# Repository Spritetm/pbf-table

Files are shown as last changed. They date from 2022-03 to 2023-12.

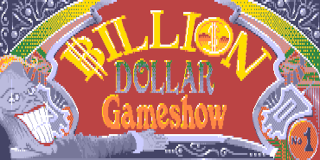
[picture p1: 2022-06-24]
esp32/components/emu_esp32s3_bindings/img/table3.png

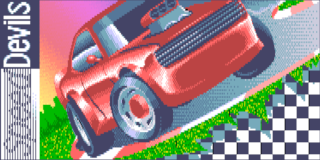
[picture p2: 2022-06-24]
esp32/components/emu_esp32s3_bindings/img/table2.png

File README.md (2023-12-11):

# Pinball Fantasies physical virtual pinball table

These are the firmware, case designs, schematics and PCB artwork
for the tiny video pinball table as described [here](https://spritesmods.com?art=pftable).

# Firmware

The firmware consists of a core emulator that emulates the main game
logic, a music player to replace the audio subsystem, and bindings
for graphics, input, and audio playback for various situations.

There are three builds for the firmware:

- Host build. For this, make sure you have the SDL2 development libraries
  installed and run ``make`` ``in the esp32/components/emu`` folder. You
  should get an ``emu`` binary using that. Use lshift, rshift, F1 and 
  enter to control the emulator.
- ESP32 build for ESP-Wrover-Kit
  This needs a wrover with >=8MiB of flash (and >=2MiB of psram). Use
  ``idf.py set-target esp32`` to select this and build and flash 
  using standard esp-idf procedures. You need buttons to control these,
  for start, plunger, left flipper and right flipper respectively, 
  connect buttons from GPIO 14, 13, 15 and 12 to ground. Audio signal
  comes out of GPIO26. Note that the game does not run at full frame
  rate on an ESP32 as the code is not optimized for that chip.
- ESP32S3 on custom PCB.
  This needs the pcbs from the ``pcb/`` and ``pcb-backbox-large/`` fabricated
  and assembled. Use ``idf.py set-target esp32s3`` and build and flash
  according to standard esp-idf procedures.

Note that the ESP32 and ESP32-S3 targets also need the Pinball 
Fantasies data files flashed; the Unix build simply needs them to
exist in the data directory. Details and helpers for obtaining these
files is in the ``data/README.md`` file. There is an example script for
flashing in ``esp32/flashdata.sh``, but it may need modifying for your
particular setup.

# Case

There is a case design (made in OpenSCAD) in the ``case`` subdirectory. 
Note that the measures are mostly what works on my 3d-printer; you 
may need to print this, see if it fits, then print again to get a 
working case.

The case parts are held together by two m3 screws fitting in two 4x5mm
brass screw thread inserts. I simply super-glued the inserts in place.

# PCB

There are three folders with Kicad PCBs: ``pcb``, ``pcb-backboard`` and 
``pcb-backboard-large``. ``pcb`` contains the main PCB which fits under
the main playfield LCD. ``pcb-backboard-large`` contains the PCB I used
for the final backboard, it interfaces with a 2.3" 320x240 LCD. ``pcb-backboard``
is a previous iteration of this; it has an 1.5" 240x240 LCD on it; it 
is included for reference only.

Note: You must use an ESP32-S3 module that has 2 or more megabyte of
QUAD PSRAM onboard. A module with octal PSRAM (or octal flash) will
not function, as it needs GPIOs that are used for other things.

# Components

Most of the components are indicated on the PCBs, but some are connected
using JST-PH or JST-XH connectors. Here's a short list of what goes where:

- J2: Speaker. I used a 4 ohm, 1.5W speaker from a laptop I had around.
- J3: Connected to an 10uF MLCC SMD cap used as the plunger sensor. The 
  plunger mechanics physically hit this cap when slamming back. See
  article on how that works.
- J4: LiIon/LiPo battery. I used a generic 1000mAh, 3.7V cell I had around.
- J5: Horizontal and vertical linear haptic actuators. These actuators are
  spare parts for a Huawei Mate 30 Pro.
- J6: Flipper and start buttons. These are a 4*5.6 HD11 microswitch each.
  Note that if you use something else, you may need to change the case model
  to make them fit.

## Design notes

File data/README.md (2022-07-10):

# Pinball Fantasies data files

This folder should contain the data files to run Pinball Fantasies, plus 'table-screens.bin' which
contains screenshots of the various tables in VGA memory dump format.

# How to get the data files

Easiest legal way:
- Buy the Pinball Gold Pack on GOG: https://www.gog.com/en/game/pinball_gold_pack
- This should make Pinball Fantasies Deluxe show up in your library. Download and install it.
- From the installed Pinball Fantasies Deluxe directory, find data/game.gog.
- Copy data/game.gog into this directory.
- Make sure you have Dosbox installed.
- Start dosbox in the current directory
- The dosbox main screen should pop up with '12 files copied' and the command prompt at the bottom
  of the screen. This means the files were succesfully extracted.
- Enter 'exit' to close dosbox.
- Remove game.gog.

Note that if you get your datafiles elsewhere and want to run this on an ESP32, you may need
to modify the filesizes in mmap_file_esp32.c.

# How to rebuild 'table-screens.bin'

The file is included in the Git repo as I imagine some screenshots easily fall under 'fair use',
but in case you want to rebuild it, here's how:

- Compile Unix build of the emulator (it's located in esp32/components/main/emu, refer to
  the README.md there to build it)
- Load up table 1
- Press 't' to dump a screenshot of the table as vram.bin and vram.pal
- Rename those files to vram1.bin and vram1.pal
- Repeat for tables 2, 3, 4
- cat vram1.bin vram1.pal vram2.bin vram2.pal vram3.bin vram3.pal vram4.bin vram4.pal > table-screens.bin

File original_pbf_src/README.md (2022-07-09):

These are the sources available from
https://github.com/historicalsource/pinballfantasies
but re-encoded into UTF8, plus some lines translated from
Swedish to english, plus a failed attempt to get this mess 
to assemble. I'll leave the Makefile and other notes in place
in case someone else wants to have a go at it.

Step 1: iconv -f CP850 -t utf-8 [all-files]
Step 2: swedish -> english

'should be compatible' masm variant:
uasm - https://github.com/Terraspace/UASM but check PRs on compile fixes
make using 'make -f gccLinux64.mak'

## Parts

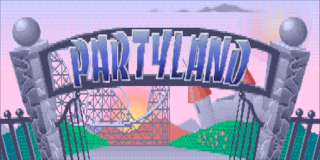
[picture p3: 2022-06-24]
esp32/components/emu_esp32s3_bindings/img/table1.png

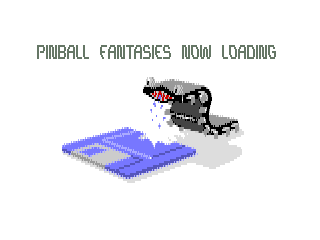
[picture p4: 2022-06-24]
esp32/components/emu_esp32s3_bindings/img/loading.png

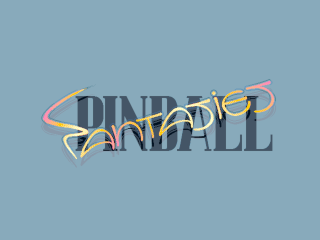
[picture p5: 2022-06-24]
esp32/components/emu_esp32s3_bindings/img/pf.png

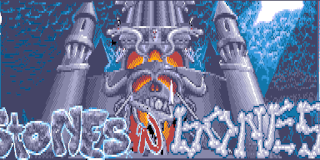
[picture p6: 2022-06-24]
esp32/components/emu_esp32s3_bindings/img/table4.png

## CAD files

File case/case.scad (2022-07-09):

/*
 * ----------------------------------------------------------------------------
 * "THE BEER-WARE LICENSE" (Revision 42):
 * Jeroen Domburg <jeroen@spritesmods.com> wrote this file. As long as you retain 
 * this notice you can do whatever you want with this stuff. If we meet some day, 
 * and you think this stuff is worth it, you can buy me a beer in return. 
 * ----------------------------------------------------------------------------
 */


//build_model selects what to render:
//0 - Body, backbox and button assembly cutout
//1 - Body
//2 - Backbox
//3 - Button assembly
//4 - Smattering of buttons. Pick the one that has a comfortable length. Need to cut it at the stem, the flat cylinder at the base is only for printability
//5 - A foot. Need to cut at the stem,the flat cylinder at the base is only for printability. You need four of these.
//Note that the build also uses four 2mm diameter brass rods for the legs, and some 1mm brass rod and a spring in the plunger assembly. The 1mm brass rods are also used to fix the buttons in place.
build_model=0;

mainlcd_w=42.8;
mainlcd_h=74.9;
mainlcd_lip=1;
mainlcd_extra_lip_bottom=5;
mainlcd_th=4.2; //including pcb
toplcd_w=52.8+1;
toplcd_h=46.4;
toplcd_th=2.9; //ex pcb
toplcd_pcbh=48+1.5;
toplcd_conh=9;
toplcd_conw=13.7;
toplcd_pcbth=1.7;
toplcd_conny=mainlcd_h+0.5;
toplcd_lip=1;
toplcd_slotw=(toplcd_pcbth+toplcd_th+0.5);
wall_th=2;
tolerance=0.2;
plunger_fhd=15;
plunger_bhd=15;
plunger_hw=7;
plunger_d=1.2;
plunger_height=26; //height of the actual plunger
plunger_asm_height=13; //height of the assembly
plunger_asm_offset_y=12;

insert_d=5;
insert_h=4;
insert_dist=25;

btn_l=5.9;
btn_w=4.4;
btn_h=1.7; //note: ex smd 'feet'
btn_pdia=1; //plunger dia
btn_plen=2.3; //length of plunger

knob_d=5;
knob_small_d=2.5;

speaker_w=27;
speaker_l=16;
speaker_d=1.5;
speaker_grille_dist=3;
speaker_grille_width=1;
$fn=50;


mscale=(mainlcd_w+(wall_th-mainlcd_lip)*2)/560;
pinball_base_w=560*mscale;
//pinball_base_l=1315*mscale; //official pb measure
pinball_base_l=1020*mscale+1.5; //looks better with lcd
pinball_base_minh=400*mscale;
pinball_base_maxh=605*mscale; //unused; see case_back_top
pinball_playfield_ang=8.875;

backhole_h=25;
backhole_w=pinball_base_w-2*wall_th;
case_back_top=11.0;

topbox_depth=10;

buttons_z=-11;
buttons_y=wall_th*6;

startbutton_len=buttons_y-wall_th+tolerance;

feet_d=2;
feethole_l=10;
feet_ang=12;
fq_th=4; //size of cube that holds the feet hole on the inside of the case

lact_l=15.3;
lact_w=8.2;
lact_h=2.6;
lact_tab_w=4;
lact_tab_off=3.3;


if (build_model==0) {
    intersection() {
        union() {
            pinball_body();
            translate([-mainlcd_w/2,0,-mainlcd_lip]) rotate([  pinball_playfield_ang, 0, 0]) translate([0,wall_th,-mainlcd_th]) scale(0.999) color("red") pcb();
            translate([0,pinball_base_l-topbox_depth,case_back_top]) backbox();

            translate([0,toplcd_conny,case_back_top]) color("red") backbox_stuff();
            translate([0,buttons_y,buttons_z]) button_assembly_thing();
        }
        translate([0,-100,-100]) cube([200,200,200]);
    }
} else if (build_model==1) {
    pinball_body();
} else if (build_model==2) {
    backbox();
} else if (build_model==3) {
    button_assembly_thing();
} else if (build_model==4) {
    translate([0,-6,0]) btnknob(9.5);
    translate([6,-6,0]) btnknob(9.5);
    translate([12,-6,0]) btnknob(8.5);
    translate([0,0,0]) btnknob(8.5);
    translate([6,0,0]) btnknob(7.5);
    translate([12,0,0]) btnknob(7.5);
    translate([0,6,0]) btnknob(8);
    translate([6,6,0]) btnknob(8);
    translate([12,6,0]) btnknob(9);
    translate([0,12,0]) btnknob(9);
    translate([6,12,0]) btnknob(10);
    translate([12,12,0]) btnknob(10);    
} else if (build_model==5) {
    foot();
}


module foot() {
    difference() {
        union() {
            hull() {
                sphere(d=4);
                cylinder(d=3, h=5);
            }
            cylinder(d=3, h=10);
        }
        cylinder(d=2, h=10);
        translate([0,0,7])rotate([90,0,0]) cylinder(d=0.7, h=3);
    }
    translate([0,0,8]) cylinder(d=10, h=2);
}


module pwrknob() {
    difference() {
        union() {
            translate([-1.5,0,-1]) cube([4.5,3.5,6+1]);    
            translate([-1.5-2,-2,-2.7]) cube([4.5+4,3.5+4,2.7]);        translate([-1.5-2,-2.5,-5]) cube([4.5+4,2.5,5]);
        }
        translate([0,0.4,-5]) cube([1.6,2,5]);

    }
}

module btnknob(length) {
    stem_len=8;
    rot_d=10;
    cylinder(h=1, d=knob_d);
    cylinder(h=stem_len+1, d=knob_small_d-tolerance*2);
    translate([0,0,stem_len]) cylinder(h=1, d1=knob_small_d-tolerance*2, d2=knob_d-tolerance*2);
    difference() {
        intersection() {
            translate([0,0,stem_len+1]) cylinder(h=length*2, d=knob_d-tolerance*2);
            translate([0,0,stem_len+length-rot_d/2]) sphere(d=rot_d);
        }
        hull() {
            translate([0,0,stem_len+2.2]) rotate([90,0,0]) cylinder(h=10, d=1.2, center=true);
            translate([0,0,stem_len+2.2+3]) rotate([90,0,0]) cylinder(h=10, d=1.2, center=true);
        }
    }
}


module button_assembly_thing() {
    difference() {
        btnholder_l=btn_l+wall_th/2;
        btnholder_w=knob_d+wall_th/2;
        union() {
           translate([-(btnholder_l+btnholder_w/2), 0, 0]) rotate([0,0,90]) button_assembly_pos(mainlcd_w/2-(btnholder_l+btnholder_w/2)-wall_th/2);
            translate([(btnholder_l+btnholder_w/2), 0, 0]) rotate([0,0,-90]) button_assembly_pos(mainlcd_w/2-(btnholder_l+btnholder_w/2)-wall_th/2);
            rotate([0,0,180]) button_assembly_pos(startbutton_len);
        }
        union() {
            translate([-(btnholder_l+btnholder_w/2), 0, 0]) rotate([0,0,90]) button_assembly_neg(mainlcd_w/2-(btnholder_l+btnholder_w/2)-wall_th/2);
            translate([(btnholder_l+btnholder_w/2), 0, 0]) rotate([0,0,-90]) button_assembly_neg(mainlcd_w/2-(btnholder_l+btnholder_w/2)-wall_th/2);
            rotate([0,0,180]) button_assembly_neg(startbutton_len);
        }
    }
}

module button_assembly_relief_thing() {
    btnholder_l=btn_l+wall_th/2;
    btnholder_w=knob_d+wall_th/2;
    translate([-(btnholder_l+btnholder_w/2), 0, 0]) rotate([0,0,90]) button_assembly_relief(mainlcd_w/2-(btnholder_l+btnholder_w/2)-wall_th/2);
    translate([(btnholder_l+btnholder_w/2), 0, 0]) rotate([0,0,-90]) button_assembly_relief(mainlcd_w/2-(btnholder_l+btnholder_w/2)-wall_th/2);
    rotate([0,0,180]) button_assembly_relief(startbutton_len);

}


module button_assembly_pos(length) {
    //Tray for switch
    translate([-(knob_d+wall_th)/2,-btn_l-wall_th/2,-knob_d+btn_h/2]) cube([knob_d+wall_th, btn_l+wall_th/2+length, knob_d]);
    //thing actual button is in
    translate([-(knob_d+wall_th)/2, wall_th/2, -(knob_d+wall_th)/2]) cube([knob_d+wall_th, length-wall_th/2, knob_d+wall_th]);
}

module button_assembly_neg(length) {
    //cutout for button
    translate([0,-btn_l/2,1]) cube([btn_w, btn_l, btn_h+2], center=true);
    //3mm shaft
    rotate([-90,0,0]) translate([0,0,-.1]) cylinder(d=knob_small_d+tolerance, h=length+1);
    //5mm shaft
    rotate([-90,0,0]) translate([0,0,btn_plen*2]) cylinder(d=knob_d+tolerance, h=length+wall_th*2);
    //square relief
    //translate([-(knob_d+tolerance)/2,btn_plen*2,0]) cube([knob_d+tolerance, length, knob_d]);
    //pin for holding btn
    translate([0,btn_plen*2+2+2.5,0]) rotate([0,90,0]) cylinder(d=1.1, h=knob_d+wall_th*3, center=true);
}

module button_assembly_relief(length) {
    //Tray for switch
    translate([-(knob_d+wall_th)/2-tolerance,-btn_l-wall_th/2,-knob_d+btn_h/2-tolerance]) cube([knob_d+wall_th+tolerance*2, btn_l+wall_th/2+length+tolerance, knob_d+tolerance*2]);
    //thing actual button is in
    translate([-(knob_d+wall_th)/2-tolerance, wall_th/2, -(knob_d+wall_th)/2-tolerance]) cube([knob_d+wall_th+tolerance*2, length-wall_th/2+tolerance, knob_d+wall_th+tolerance*2]);
    //5mm shaft
    rotate([-90,0,0]) translate([0,0,btn_plen*2]) cylinder(d=knob_d+tolerance, h=length+wall_th*2);
}


module screwhole() {
    rotate([-90,0,0]) union() {
        translate([0,0,-10]) cylinder(h=20, d=3.5);
        cylinder(h=10, d=5.3+0.3);
    }
}
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

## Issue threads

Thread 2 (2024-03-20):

Using a slightly different screen model (different pinout, 16bit)

opengiveback, 2024-03-20:
Hi, I intend on using the only reasonably priced screen with 360*640 and 40 wire connection I found available, same controller though. But only 16 bits for data R5G6B5. And some difference in Vcc position, lacking SPI but I2C present...
I guess I only need to rewire the FRC connector to suit the new screen (omit R6 and B6, Vcc), and find the way to init via I2C, then (perhaps) rework the bit of code that sends the 18bit color to send 16 bit instead (or just omit LSB of R and B and be content with it :) ).
But I am not the Espressif engineer here, nor have I read all the code, so here I am just asking if that seems to be enough modification of PCB and code to make it work. Or am I missing something?
Of course I shall either publish the modification in OpenSource, or provide beer as per BeerWare license. :)

Spritetm, 2024-03-21:
It should be possible to adapt the code to that display, indeed in the way you describe. Note that for this project, the angle at which you can view the display is kinda important as you tend to look at it at a 'weird' angle: make sure that your display has a wide-angle view. I made the mistake of not doing that with the top display, and it's sometimes nigh unreadable.

opengiveback, 2024-03-21:
Thanks for your expert confirmation and suggestions, author of the greatest little pinball machine ever :)
The specs on the viewing angle seem same as on the one you used (IPS, 178 degree view), and having the same controller for the display also it seems to be same physical display with different wiring configuration... either way, only others I found are more than an order of magnitude more expensive, so if it turns out they did compromise on view angles, I'll just change the angle of the screen in the product enclosure 5 degrees or so... and that should then be enough even if the screen is the lowest quality IPS screen there is... thanks again for your response

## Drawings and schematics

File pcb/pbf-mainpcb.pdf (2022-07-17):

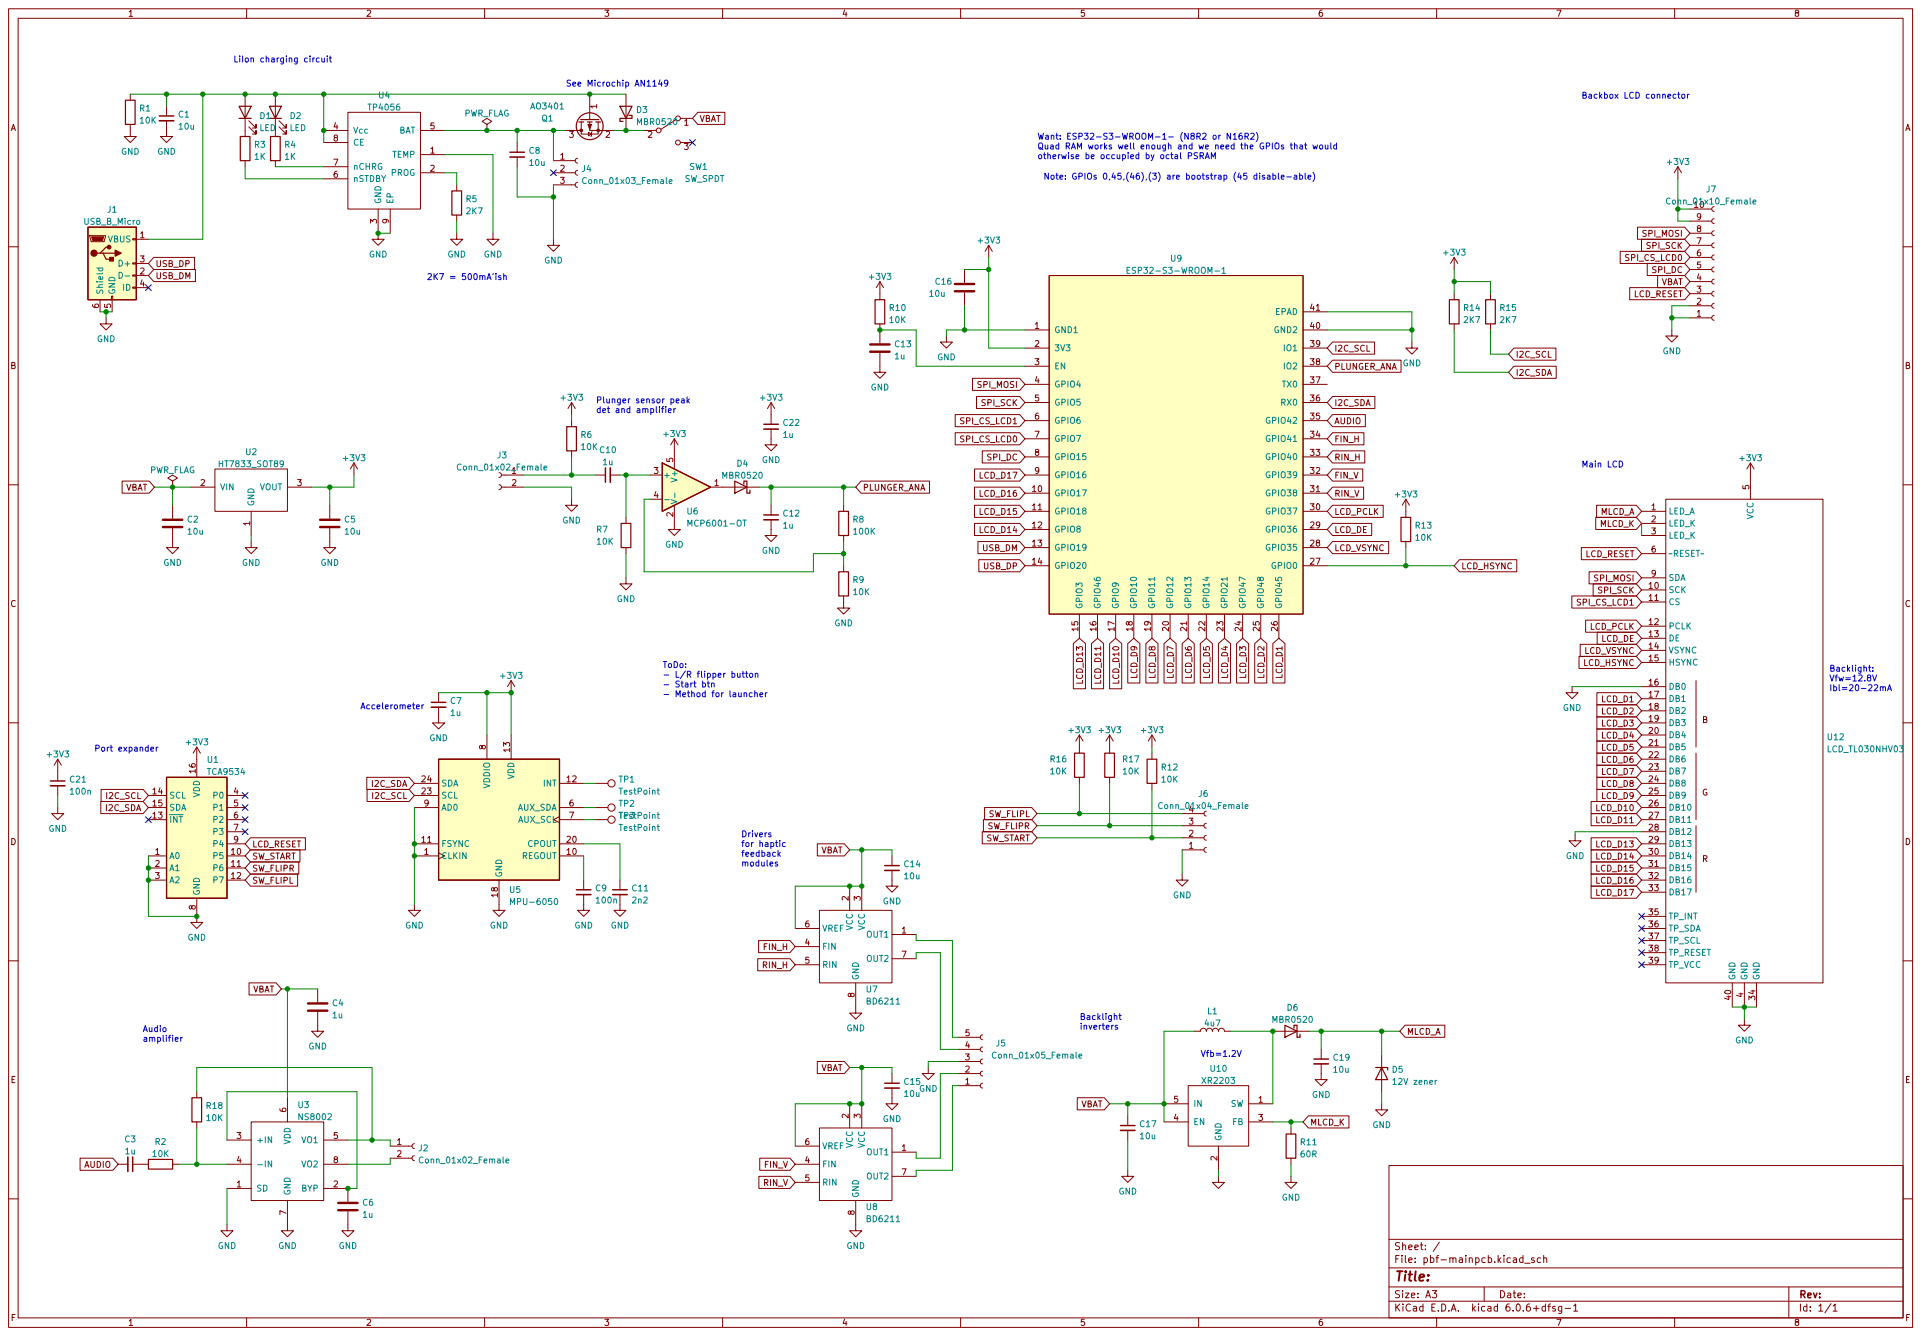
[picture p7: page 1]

Backbox LCD connector See Microchip AN1149
D3MBR0520 V- 2 V+

Want: ESP32-S3-WROOM-1- (N8R2 or N16R2)
Quad RAM works well enough and we need the GPIOs that would
otherwise be occupied by octal PSRAM

Note: GPIOs 0,45,(46),(3) are bootstrap (45 disable-able)

- Method for launcher Audio

3 FIN 4 RIN 5 VREF 6 OUT2 7 GND

File: pbf-mainpcb.kicad_sch Sheet: /

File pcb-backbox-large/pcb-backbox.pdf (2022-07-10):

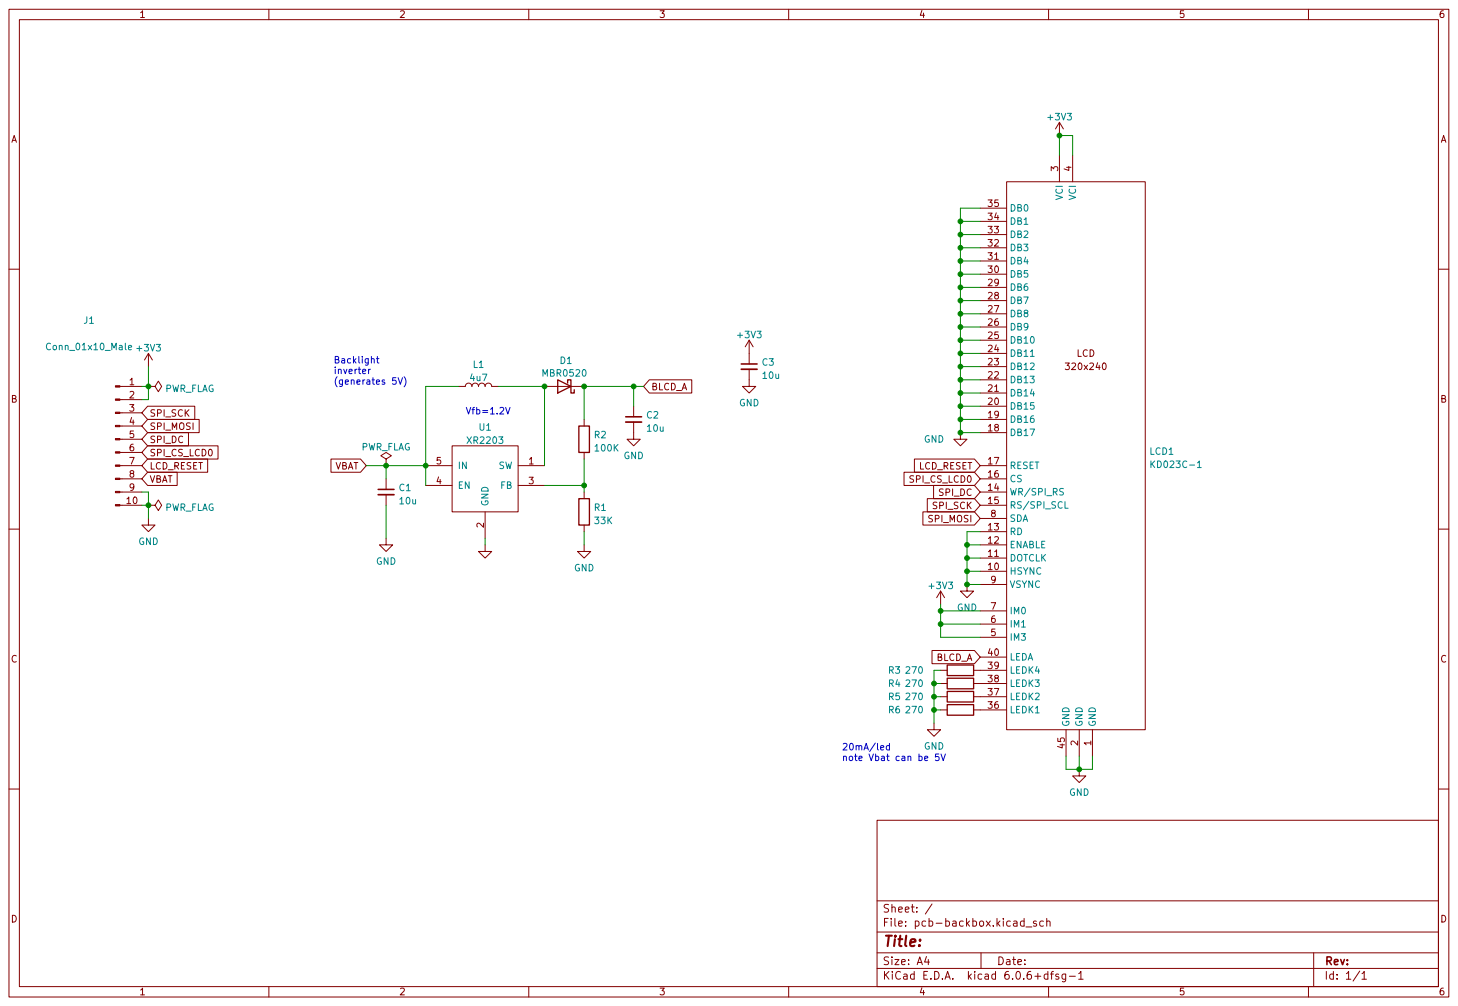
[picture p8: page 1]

20mA/led
note Vbat can be 5V

File: pcb-backbox.kicad_sch Sheet: /

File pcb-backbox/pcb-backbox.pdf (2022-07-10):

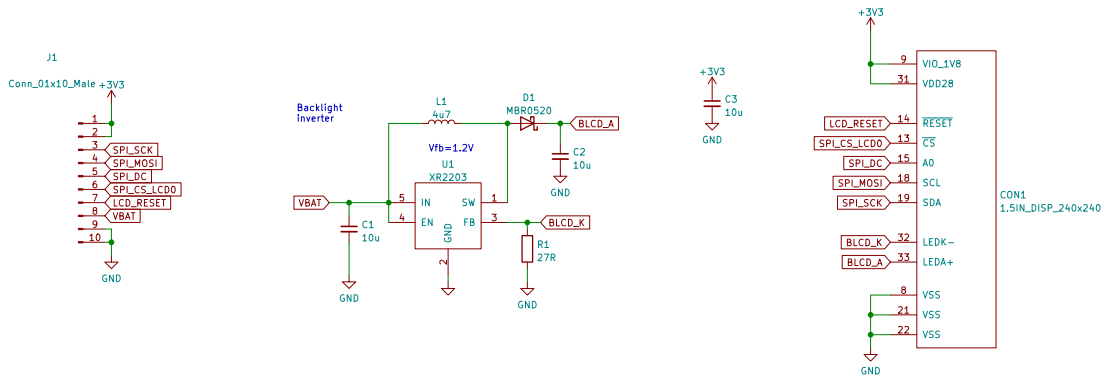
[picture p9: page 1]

File: pcb-backbox.kicad_sch Sheet: /
Id: 1/1 Title:

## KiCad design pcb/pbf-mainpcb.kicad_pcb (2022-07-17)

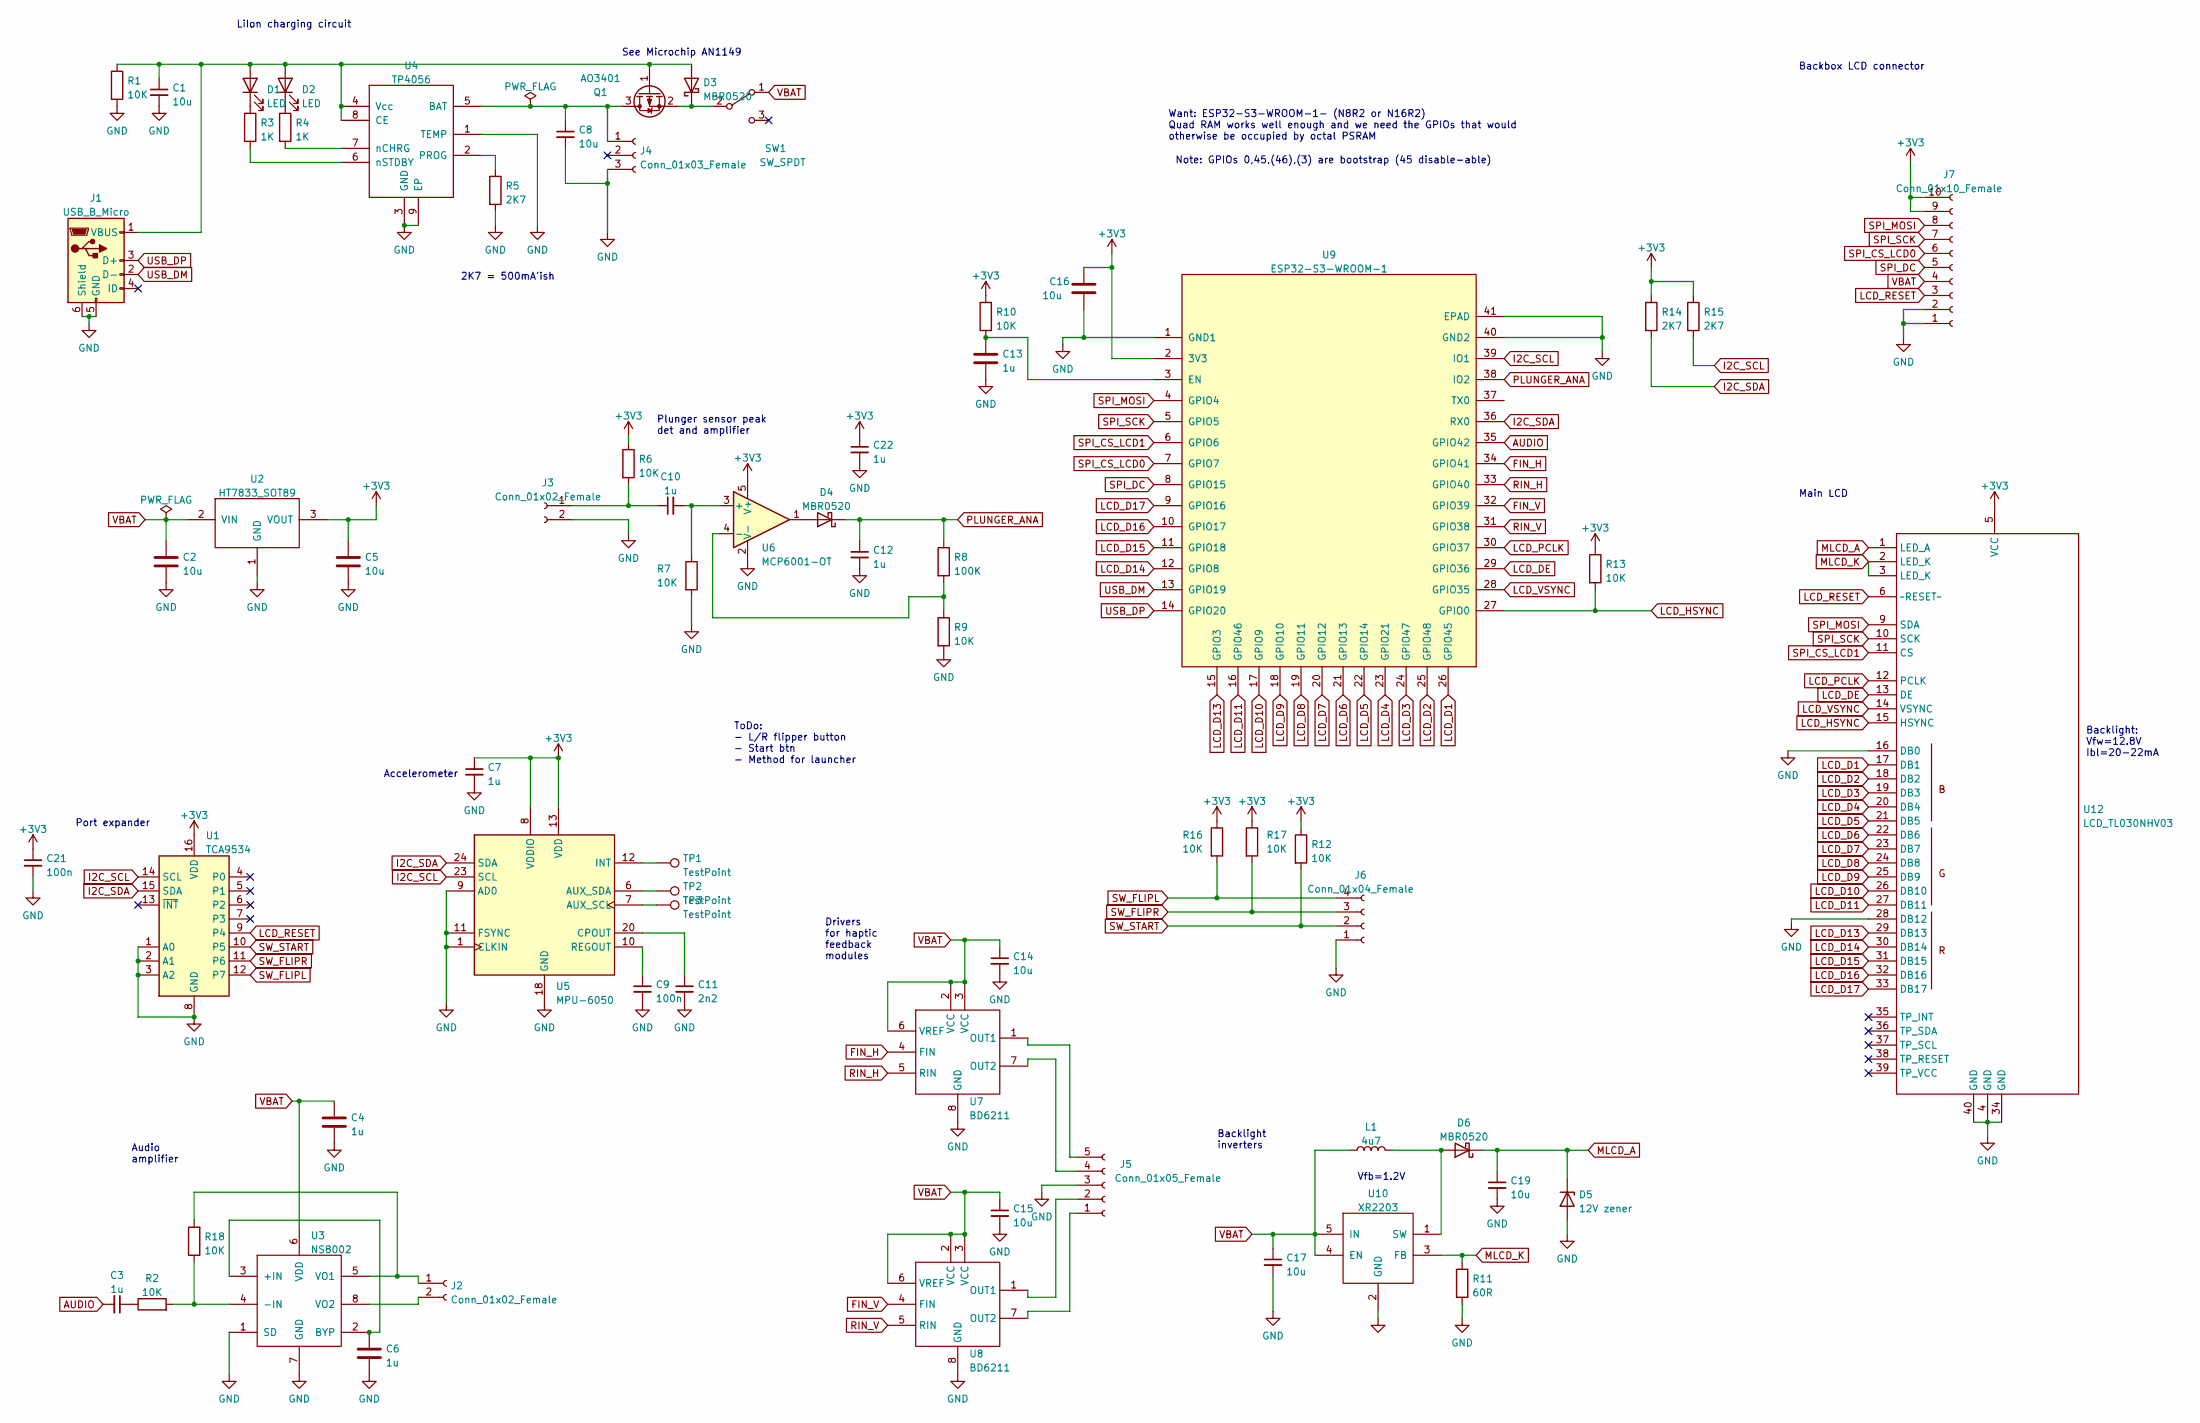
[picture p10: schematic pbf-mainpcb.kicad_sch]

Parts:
C1, C2, C5, C8, C14, C15, C16, C17, C19: 10u; C_0805_2012Metric
C3, C4, C6, C7, C10, C12, C13, C22: 1u; C_0603_1608Metric
C9, C21: 100n; C_0603_1608Metric
C11: 2n2; C_0603_1608Metric
D1, D2: LED; LED_0603_1608Metric
D3, D4, D6: MBR0520; D_SOD-123
D5: 12V zener; D_MELF
J1: USB_B_Micro; USB_Micro-B_China_MK5P
J2: Conn_01x02_Female; JST_XH_B2B-XH-AM_1x02_P2.50mm_Vertical
J3: Conn_01x02_Female; JST_PH_B2B-PH-K_1x02_P2.00mm_Vertical
J4: Conn_01x03_Female; JST_PH_B3B-PH-K_1x03_P2.00mm_Vertical
J5: Conn_01x05_Female; JST_PH_B5B-PH-K_1x05_P2.00mm_Vertical
J6: Conn_01x04_Female; JST_PH_B4B-PH-K_1x04_P2.00mm_Vertical
J7: Conn_01x10_Female; PinHeader_2x05_P2.54mm_Horizontal
L1: 4u7; L_1008_2520Metric
Q1: AO3401; SOT-23
R1, R2, R6, R7, R9, R10, R12, R13, R16, R17, R18: 10K; R_0603_1608Metric
R3, R4: 1K; R_0603_1608Metric
R5, R14, R15: 2K7; R_0603_1608Metric
R8: 100K; R_0603_1608Metric
R11: 60R; R_0603_1608Metric
SW1: SW_SPDT; SW_SPDT_PCM12
TP1, TP2, TP3: TestPoint; TestPoint_Pad_1.0x1.0mm
U1: TCA9534; TSSOP-16_4.4x5mm_P0.65mm
U2: HT7833_SOT89; SOT-89-3
U3: NS8002; SOP-8_3.9x4.9mm_P1.27mm
U4: TP4056; SOIC-8-1EP_3.9x4.9mm_P1.27mm_EP2.29x3mm
U5: MPU-6050; InvenSense_QFN-24_4x4mm_P0.5mm
U6: MCP6001-OT; SOT-23-5
U7, U8: BD6211; SOP-8_3.9x4.9mm_P1.27mm
U9: ESP32-S3-WROOM-1
U10: XR2203; SOT-23-5
U12: LCD_TL030NHV03; TE_4-1734839-0_1x40-1MP_P0.5mm_Horizontal_Reversed

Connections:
+3V3: C5.1, C7.1, C16.1, C21.1, C22.1, J7.9, J7.10, R6.1, R10.2, R12.1, R13.1, R14.1, R15.1, R16.1, R17.1, U1.16 (VDD), U2.3 (VOUT), U5.8 (VDDIO), U5.13 (VDD), U6.5 (V+), U9.2 (3V3), U12.5 (VCC)
AUDIO: C3.2, U9.35 (GPIO42)
FIN_H: U7.4 (FIN), U9.34 (GPIO41)
FIN_V: U8.4 (FIN), U9.32 (GPIO39)
I2C_SCL: R15.2, U1.14 (SCL), U5.23 (SCL), U9.39 (IO1)
I2C_SDA: R14.2, U1.15 (SDA), U5.24 (SDA), U9.36 (RX0)
LCD_D1: U9.26 (GPIO45), U12.17 (DB1)
LCD_D2: U9.25 (GPIO48), U12.18 (DB2)
LCD_D3: U9.24 (GPIO47), U12.19 (DB3)
LCD_D4: U9.23 (GPIO21), U12.20 (DB4)
LCD_D5: U9.22 (GPIO14), U12.21 (DB5)
LCD_D6: U9.21 (GPIO13), U12.22 (DB6)
LCD_D7: U9.20 (GPIO12), U12.23 (DB7)
LCD_D8: U9.19 (GPIO11), U12.24 (DB8)
LCD_D9: U9.18 (GPIO10), U12.25 (DB9)
LCD_D10: U9.17 (GPIO9), U12.26 (DB10)
LCD_D11: U9.16 (GPIO46), U12.27 (DB11)
LCD_D13: U9.15 (GPIO3), U12.29 (DB13)
LCD_D14: U9.12 (GPIO8), U12.30 (DB14)
LCD_D15: U9.11 (GPIO18), U12.31 (DB15)
LCD_D16: U9.10 (GPIO17), U12.32 (DB16)
LCD_D17: U9.9 (GPIO16), U12.33 (DB17)
LCD_DE: U9.29 (GPIO36), U12.13 (DE)
LCD_HSYNC: R13.2, U9.27 (GPIO0), U12.15 (HSYNC)
LCD_PCLK: U9.30 (GPIO37), U12.12 (PCLK)
LCD_RESET: J7.3, U1.9 (P4), U12.6 (~RESET~)
LCD_VSYNC: U9.28 (GPIO35), U12.14 (VSYNC)
MLCD_A: C19.1, D5.1 (K), D6.1 (K), U12.1 (LED_A)
MLCD_K: R11.1, U10.3 (FB), U12.2 (LED_K), U12.3 (LED_K)
unnamed: C1.1, D1.2 (A), D2.2 (A), D3.2 (A), J1.1 (VBUS), Q1.1 (G), R1.1, U4.4 (Vcc), U4.8 (CE)
unnamed: C3.1, R2.1
unnamed: C6.1, U3.2 (BYP), U3.3 (+IN)
unnamed: C8.1, J4.1, Q1.3 (D), U4.5 (BAT)
unnamed: C9.1, U5.10 (REGOUT)
unnamed: C10.1, J3.1, R6.2
unnamed: C10.2, R7.1, U6.3 (+)
unnamed: C11.1, U5.20 (CPOUT)
unnamed: C13.1, R10.1, U9.3 (EN)
unnamed: D1.1 (K), R3.1
unnamed: D2.1 (K), R4.1
unnamed: D3.1 (K), Q1.2 (S), SW1.2 (B)
unnamed: D4.2 (A), U6.1
unnamed: D6.2 (A), L1.2, U10.1 (SW)
unnamed: J2.1, R18.2, U3.5 (VO1)
unnamed: J2.2, U3.8 (VO2)
unnamed: J5.1, U8.7 (OUT2)
unnamed: J5.2, U8.1 (OUT1)
unnamed: J5.4, U7.7 (OUT2)
unnamed: J5.5, U7.1 (OUT1)
unnamed: R3.2, U4.6 (nSTDBY)
unnamed: R4.2, U4.7 (nCHRG)
unnamed: R5.1, U4.2 (PROG)
unnamed: R8.2, R9.1, U6.4 (-)
unnamed: TP1.1, U5.12 (INT)
unnamed: TP2.1, U5.6 (AUX_SDA)
unnamed: TP3.1, U5.7 (AUX_SCL)
unnamed: R2.2, R18.1, U3.4 (-IN)
PLUNGER_ANA: C12.1, D4.1 (K), R8.1, U9.38 (IO2)
RIN_H: U7.5 (RIN), U9.33 (GPIO40)
RIN_V: U8.5 (RIN), U9.31 (GPIO38)
SPI_CS_LCD0: J7.6, U9.7 (GPIO7)
SPI_CS_LCD1: U9.6 (GPIO6), U12.11 (CS)
SPI_DC: J7.5, U9.8 (GPIO15)
SPI_MOSI: J7.8, U9.4 (GPIO4), U12.9 (SDA)
SPI_SCK: J7.7, U9.5 (GPIO5), U12.10 (SCK)
SW_FLIPL: J6.4, R16.2, U1.12 (P7)
SW_FLIPR: J6.3, R17.2, U1.11 (P6)
SW_START: J6.2, R12.2, U1.10 (P5)
USB_DM: J1.2 (D-), U9.13 (GPIO19)
USB_DP: J1.3 (D+), U9.14 (GPIO20)
VBAT: C2.1, C4.1, C14.1, C15.1, C17.1, J7.4, L1.1, SW1.1 (A), U2.2 (VIN), U3.6 (VDD), U7.2 (VCC), U7.3 (VCC), U7.6 (VREF), U8.2 (VCC), U8.3 (VCC), U8.6 (VREF), U10.4 (EN), U10.5 (IN)

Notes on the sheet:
Plunger sensor peak det and amplifier
Port expander
Backbox LCD connector
ToDo: - L/R flipper button - Start btn - Method for launcher
Vfb=1.2V
Backlight inverters
LiIon charging circuit
Main LCD
Accelerometer
2K7 = 500mA'ish
Audio amplifier
Want: ESP32-S3-WROOM-1- (N8R2 or N16R2) Quad RAM works well enough and we need the GPIOs that would otherwise be occupied by octal PSRAM
Backlight: Vfw=12.8V Ibl=20-22mA
Drivers for haptic feedback modules
See Microchip AN1149
Note: GPIOs 0,45,(46),(3) are bootstrap (45 disable-able)

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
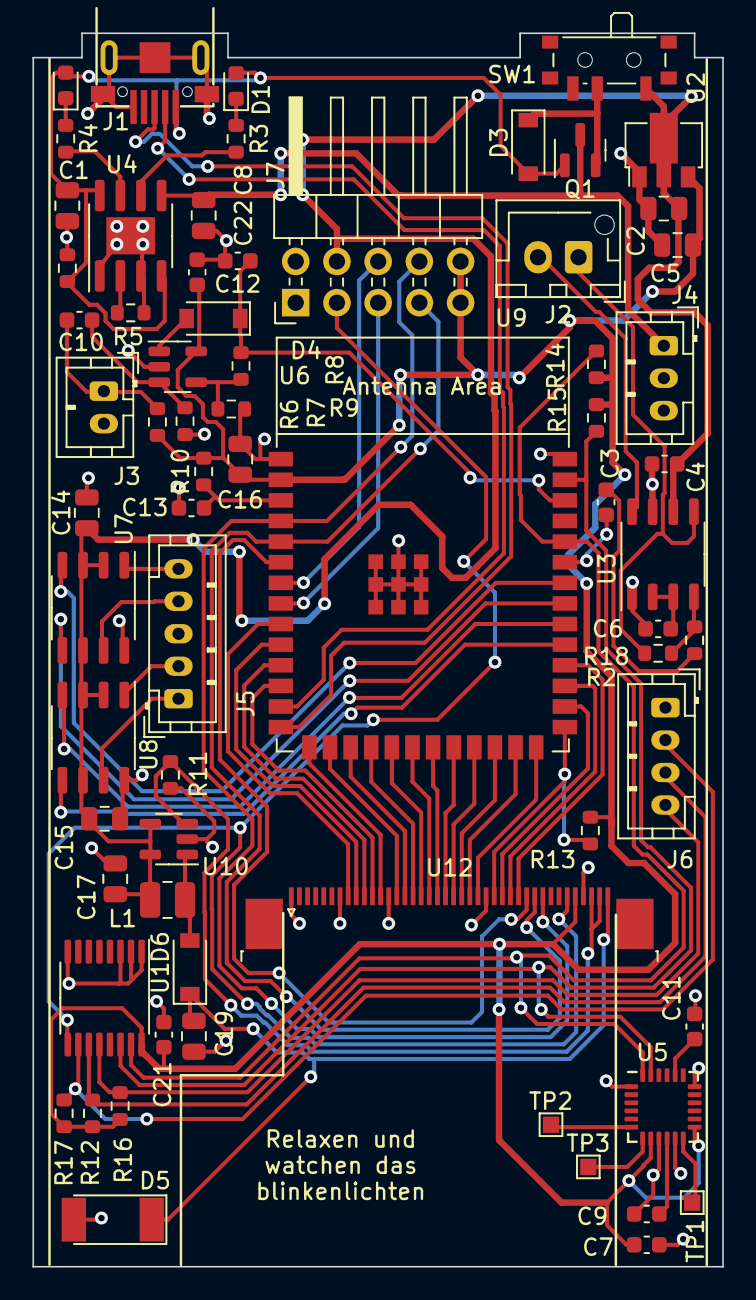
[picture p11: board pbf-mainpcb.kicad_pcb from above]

Board: 2 copper layers, 42.5 x 76.0 mm, 68 parts (0 on the bottom side), 72 nets.

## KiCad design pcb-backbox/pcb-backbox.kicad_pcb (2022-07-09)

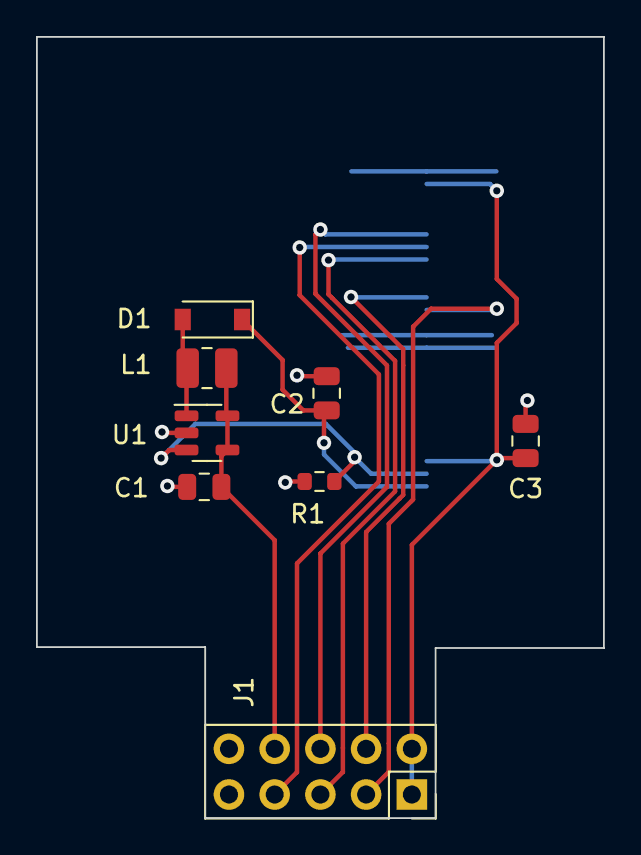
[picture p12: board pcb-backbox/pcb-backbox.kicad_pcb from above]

Board: 2 copper layers, 31.5 x 43.4 mm, 9 parts (1 on the bottom side), 11 nets.

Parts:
C1, C2, C3: 10u; C_0805_2012Metric
CON1: 1.5IN_DISP_240x240; lcd_1.5in_vert_hotbar
D1: MBR0520; D_SOD-123
J1: Conn_01x10_Male; PinSocket_2x05_P2.54mm_Vertical
L1: 4u7; L_1008_2520Metric
R1: 27R; R_0603_1608Metric
U1: XR2203; SOT-23-5

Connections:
+3V3: C3.1, CON1.9 (VIO_1V8), CON1.31 (VDD28), J1.1, J1.2
BLCD_A: C2.1, CON1.33 (LEDA+), D1.1 (K)
BLCD_K: CON1.32 (LEDK-), R1.1, U1.3 (FB)
GND: C1.2, C2.2, C3.2, CON1.8 (VSS), CON1.21 (VSS), CON1.22 (VSS), J1.9, J1.10, R1.2, U1.2 (GND)
LCD_RESET: CON1.14 (~RESET), J1.7
unnamed: D1.2 (A), L1.2, U1.1 (SW)
SPI_CS_LCD0: CON1.13 (~CS), J1.6
SPI_DC: CON1.15 (A0), J1.5
SPI_MOSI: CON1.18 (SCL), J1.4
SPI_SCK: CON1.19 (SDA), J1.3
VBAT: C1.1, J1.8, L1.1, U1.4 (EN), U1.5 (IN)

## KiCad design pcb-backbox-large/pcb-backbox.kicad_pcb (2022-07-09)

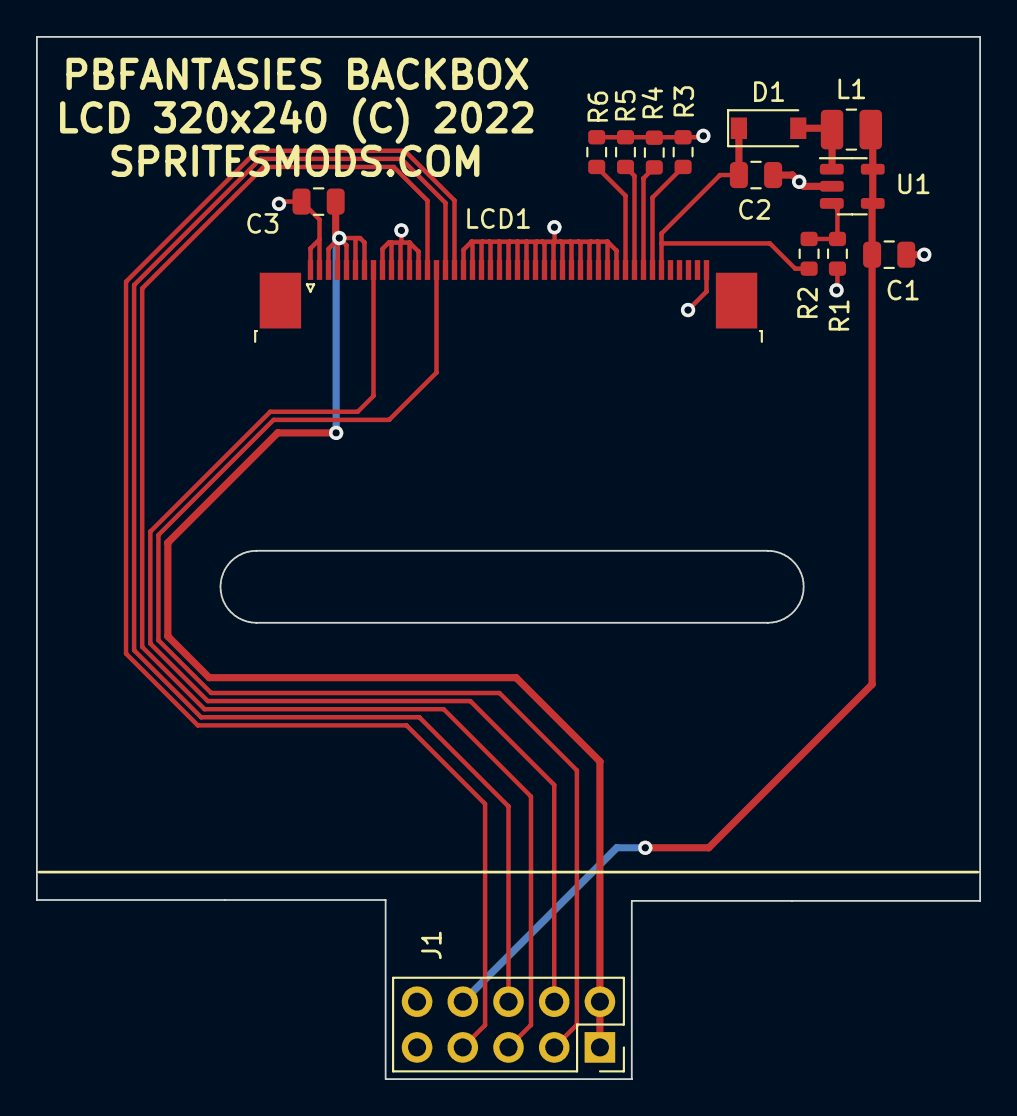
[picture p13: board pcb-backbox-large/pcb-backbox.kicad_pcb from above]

Board: 2 copper layers, 52.4 x 57.9 mm, 14 parts (0 on the bottom side), 15 nets.

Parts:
C1, C2, C3: 10u; C_0805_2012Metric
D1: MBR0520; D_SOD-123
J1: Conn_01x10_Male; PinSocket_2x05_P2.54mm_Vertical
L1: 4u7; L_1008_2520Metric
LCD1: KD023C-1; TE_4-1734839-5_1x45-1MP_P0.5mm_Horizontal
R1: 33K; R_0603_1608Metric
R2: 100K; R_0603_1608Metric
R3, R4, R5, R6: 270; R_0603_1608Metric
U1: XR2203; SOT-23-5

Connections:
+3V3: C3.1, J1.1, J1.2, LCD1.3 (VCI), LCD1.4 (VCI), LCD1.5 (IM3), LCD1.6 (IM1), LCD1.7 (IM0)
BLCD_A: C2.1, D1.1 (K), LCD1.40 (LEDA), R2.1
GND: C1.2, C2.2, C3.2, J1.9, J1.10, LCD1.1 (GND), LCD1.2 (GND), LCD1.9 (VSYNC), LCD1.10 (HSYNC), LCD1.11 (DOTCLK), LCD1.12 (ENABLE), LCD1.13 (RD), LCD1.18 (DB17), LCD1.19 (DB16), LCD1.20 (DB15), LCD1.21 (DB14), LCD1.22 (DB13), LCD1.23 (DB12), LCD1.24 (DB11), LCD1.25 (DB10), LCD1.26 (DB9), LCD1.27 (DB8), LCD1.28 (DB7), LCD1.29 (DB6), LCD1.30 (DB5), LCD1.31 (DB4), LCD1.32 (DB3), LCD1.33 (DB2), LCD1.34 (DB1), LCD1.35 (DB0), LCD1.45 (GND), R1.2, R3.1, R4.1, R5.1, R6.1, U1.2 (GND)
LCD_RESET: J1.7, LCD1.17 (RESET)
unnamed: D1.2 (A), L1.2, U1.1 (SW)
unnamed: LCD1.36 (LEDK1), R6.2
unnamed: LCD1.37 (LEDK2), R5.2
unnamed: LCD1.38 (LEDK3), R4.2
unnamed: LCD1.39 (LEDK4), R3.2
unnamed: R1.1, R2.2, U1.3 (FB)
SPI_CS_LCD0: J1.6, LCD1.16 (CS)
SPI_DC: J1.5, LCD1.14 (WR/SPI_RS)
SPI_MOSI: J1.4, LCD1.8 (SDA)
SPI_SCK: J1.3, LCD1.15 (RS/SPI_SCL)
VBAT: C1.1, J1.8, L1.1, U1.4 (EN), U1.5 (IN)

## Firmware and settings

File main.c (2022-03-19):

#include <stdio.h>
#include <stdlib.h>
#include <stdint.h>
#include "cpu.h"
#include <string.h>
#include "gfx.h"
#include "cpu_addr_space.h"
#include "ibxm/ibxm.h"
#include "hexdump.h"
#include "trace.h"
#include "scheduler.h"
#include "load_exe.h"

//Note: this code assumes a little-endian host machine. It messes up when run on a big-endian one.

#define SAMP_RATE 44100
struct module *music_module;
struct replay *music_replay;
int *music_mixbuf;
int music_mixbuf_len;
int music_mixbuf_left;

int key_pressed=0;

#define REG_AX cpu.regs.wordregs[regax]
#define REG_BX cpu.regs.wordregs[regbx]
#define REG_CX cpu.regs.wordregs[regcx]
#define REG_DX cpu.regs.wordregs[regdx]
#define REG_BP cpu.regs.wordregs[regbp]
#define REG_DS cpu.segregs[regds]
#define REG_ES cpu.segregs[reges]

int load_mz(const char *exefile, int load_start_addr);


void dump_regs() {
	printf("AX %04X  SI %04X  ES %04X\n", cpu.regs.wordregs[regax], cpu.regs.wordregs[regsi], cpu.segregs[reges]);
	printf("BX %04X  DI %04X  CS %04X\n", cpu.regs.wordregs[regbx], cpu.regs.wordregs[regdi], cpu.segregs[regcs]);
	printf("CX %04X  SP %04X  SS %04X\n", cpu.regs.wordregs[regcx], cpu.regs.wordregs[regsp], cpu.segregs[regss]);
	printf("DX %04X  BP %04X  DS %04X\n", cpu.regs.wordregs[regdx], cpu.regs.wordregs[regbp], cpu.segregs[regds]);
}

void dump_caller() {
	int sp_addr=cpu.regs.wordregs[regsp]+cpu.segregs[regss]*0x10;
	int seg=cpu_addr_space_read8(sp_addr+2)+(cpu_addr_space_read8(sp_addr+3)<<8);
	int off=cpu_addr_space_read8(sp_addr)+(cpu_addr_space_read8(sp_addr+1)<<8);
	printf("Caller: %04X:%04X\n", seg, off);
}

void timing() {
}

uint8_t vram[256*1024];
uint32_t pal[255];
int vga_seq_addr;
int vga_mask;
int vga_pal_idx;
int vga_crtc_addr;
int vga_hor=200, vga_ver=320;
int vga_startaddr;
uint8_t vga_gcregs[8];
int vga_gcindex;
uint8_t vga_latch[4];

static int keycode[]={
	0,
	0x50, //down
	0x2A, //lshift
	0x36, //rshift
	0x39, //space
	0x3b,
	0x3c,
	0x3d,
	0x3e,
	0, //test key
};

uint8_t portin(uint16_t port) {
	if (port==0x60) {
		int kc=keycode[key_pressed&0x7F];
		if (key_pressed&INPUT_RELEASE) kc|=0x80;
		key_pressed=0;
		printf("Keycode %x\n", kc);
		return kc;
	} else if (port==0x61) {
		return 0; //nothing wrong
	} else if (port==0x3CF) {
		return vga_gcregs[vga_gcindex];
	} else if (port==0x3C5) {
		//ignore, there's very little we use in there anyway
	} else {
		printf("Port read 0x%X\n", port);
		static int n=0;
		return n++;
	}
	return 0;
}

uint8_t portin16(uint16_t port) {
	printf("16-bit port read 0x%X\n", port);
}


void portout(uint16_t port, uint8_t val) {
	if (port==0x3c4) {
		vga_seq_addr=val&3;
	} else if (port==0x3c5) {
		if (vga_seq_addr==2) {
			vga_mask=val&0xf;
		}
	} else if (port==0x3c8) {
		vga_pal_idx=val*4;
	} else if (port==0x3c9) {
		int col=vga_pal_idx>>2;
		int attr=vga_pal_idx&3;
		val<<=2;  //vga palette is 6 bit per color
		if (attr==0) pal[col]=(pal[col]&0x00ffff)|(val<<16);
		if (attr==1) pal[col]=(pal[col]&0xff00ff)|(val<<8);
		if (attr==2) pal[col]=(pal[col]&0xffff00)|(val<<0);
		if (attr==2) vga_pal_idx+=2; else vga_pal_idx++;
	} else if (port==0x3ce) {
		vga_gcindex=val&7;
	} else if (port==0x3cf) {
//		if (val!=vga_gcregs[vga_gcindex]) {
//			printf("0x3C7 idx %d -> %02X\n", vga_gcindex, val);
//		}
		vga_gcregs[vga_gcindex]=val;
	} else if (port==0x3D4) {
		vga_seq_addr=val&31;
	} else if (port==0x3D5) {
		if (vga_seq_addr==1) {
			vga_hor=(val+1)*4;
		} else if (vga_seq_addr==0xC) {
			vga_startaddr=(vga_startaddr&0xff)|(val<<8);
		} else if (vga_seq_addr==0xD) {
			vga_startaddr=(vga_startaddr&0xff00)|(val);
		} else if (vga_seq_addr==0x13) {
			vga_ver=val*8;
		} else {
			printf("port 3d5 idx 0x%X val 0x%X\n", vga_seq_addr, val);
		}
	} else if (port==0x61) {
		//Keyboard port; ignore
	} else {
		printf("Port 0x%X val 0x%02X\n", port, val);
	}
}

void portout16(uint16_t port, uint16_t val) {
//	printf("Port 0x%X val 0x%04X\n", port, val);
	portout(port, val&0xff);
	portout(port+1, val>>8);
}

void vga_mem_write(int addr, uint8_t data, mem_chunk_t *ch) {
	//Pinball Fantasies uses Mode X.
	int vaddr=addr-0xA0000;
	if ((vga_gcregs[5]&3)==0) {
		if (vga_mask&1) vram[vaddr*4+0]=data;
		if (vga_mask&2) vram[vaddr*4+1]=data;
		if (vga_mask&4) vram[vaddr*4+2]=data;
		if (vga_mask&8) vram[vaddr*4+3]=data;
	} else if ((vga_gcregs[5]&3)==1) {
		for (int i=0; i<4; i++) vram[vaddr*4+i]=vga_latch[i];
	}
}

uint8_t vga_mem_read(int addr, mem_chunk_t *ch) {
	int vaddr=addr-0xA0000;
	for (int i=0; i<4; i++) vga_latch[i]=vram[vaddr*4+i];
	//note: what if multiple bits in mask are enabled?
	if (vga_mask&1) return vram[vaddr*4+0];
	if (vga_mask&2) return vram[vaddr*4+1];
	if (vga_mask&4) return vram[vaddr*4+2];
	if (vga_mask&8) return vram[vaddr*4+3];
}

void init_vga_mem() {
	cpu_addr_space_map_cb(0xa0000, 0x10000, vga_mem_write, vga_mem_read, NULL);
}

void hook_interrupt_call(uint8_t intr);

void intr_table_writefn(int addr, uint8_t data, mem_chunk_t *ch) {
	//this is supposed to be rom
	printf("Aiee, write to rom segment? (Adr %05X, data %02X)\n", addr, data);
	exit(1);
}

uint8_t intr_table_readfn(int addr, mem_chunk_t *ch) {
	int intr=(addr-0xf0000);
	if (intr<256) hook_interrupt_call(intr);
	return 0xcf; //IRET
}

void init_intr_table() {
	//Set up interrupt table so each interrupt i vectors to address (F000:i)
	for (int i=0; i<256; i++) {
		cpu_addr_space_write8(i*4+2, 0x00);
		cpu_addr_space_write8(i*4+3, 0xf0);
		cpu_addr_space_write8(i*4+0, i);
		cpu_addr_space_write8(i*4+1, 0);
	}
	//Set up some address space in ROM that the interrupt table vectors point at by default.
	//We take a read from the first 256 addresses as an interrupt request for that irq.
	cpu_addr_space_map_cb(0xf0000, 2048, intr_table_writefn, intr_table_readfn, NULL);
}

int cb_raster_int_line=0;
int cb_raster_seg=0, cb_raster_off=0;
int cb_blank_seg=0, cb_blank_off=0;
int cb_jingle_seg=0, cb_jingle_off=0;

int mouse_x=0;
int mouse_y=0;
int mouse_btn=0;
int mouse_down=0;

//this is what's indicated as 'togglaren' in the sources
typedef struct __attribute__((packed)) {
	uint8_t s_balls; //3 (0) or 5 (1). Default is 3
	uint8_t s_angle; //high (0) or low (1). Default is high.
	uint8_t s_scrolling; //medium (1), soft (2), hard (0). Default is medium.
	uint8_t s_im; //ingame music, on (0) or off (1). Default is on.
	uint8_t s_resolution; //reso, normal (0) or high (1). Default is normal.
	uint8_t s_mode; //color mode, color (0) or mono (1). Default is color.
} pref_type_t;


static pref_type_t prefs={
	.s_balls=0,
	.s_angle=0,
	.s_scrolling=1,
	.s_im=0,
	.s_resolution=0,
	.s_mode=0
};

void hook_interrupt_call(uint8_t intr) {
//	printf("Intr 0x%X\n", intr);
//	dump_regs();
	if (intr==0x21 && (REG_AX>>8)==0x4A) {
		printf("Resize block\n");
		//resize block; always allow as there's nothing in memory anyway
		REG_AX=0;
		cpu.cf=0;
	} else if (intr==0x21 && (REG_AX>>8)==0x9) {
		printf("Message\n");
	} else if (intr==0x21 && (REG_AX>>8)==0xE) {
		printf("Set default drive %c\n", 'A'+(REG_DX&0xff));
		REG_AX=0x0E00+26;
	} else if (intr==0x21 && (REG_AX>>8)==0x3B) {
		printf("Set current dir\n");
		cpu.cf=0;
	} else if (intr==0x21 && (REG_AX>>8)==0x3D) {
		printf("Open file\n");
		cpu.cf=1;
	} else if (intr==0x21 && (REG_AX>>8)==0x3E) {
		printf("Close file\n");
		cpu.cf=1;
	} else if (intr==0x21 && (REG_AX>>8)==0x3F) {
		printf("Read from file\n");
		cpu.cf=1;
	} else if (intr==0x10 && (REG_AX>>8)==0) {
		printf("Set video mode %x\n", REG_AX&0xff);
	} else if (intr==0x65) {
		//internal keyhandler: START.ASM:363
		//ax=0: first_time_ask (ret ah=first_time, bl=bannumber)
		//ax=0xffff: save bl to bannumber
		//ax=0x100: LOKALA TOGGLAREN => RESIDENTA TOGGLAREN
		//ax=0x200: RESIDENTA TOGGLAREN => LOKALA TOGGLAREN
		//(togglaren being the preferences, so save & load prefs
		//from/to es:bx)
		//ax00x12: text input
		//others: simply return scan code without side effects
		//Returns scan code in ax
		if (REG_AX==0x200) {
			int adr=(REG_ES<<4)+REG_BX;
			uint8_t *p=(uint8_t*)&prefs;
			for (int i=0; i<sizeof(prefs); i++) {
				cpu_addr_space_write8(adr++, *p++);
			}
		}
		REG_AX=0;
		printf("Key handler\n");
		dump_regs();
	} else if (intr==0x33) {
		//Mouse interrupt
		if ((REG_AX&0xff)==0) {
			REG_AX=0xFFFF; //installed
			REG_BX=2; //2 buttons
		} else if ((REG_AX&0xff)==8) {
			printf("Mouse: def vert cursor range %d to %d\n", REG_CX, REG_DX);
		} else if ((REG_AX&0xff)==0xf) {
			printf("Mouse: def mickey/pixel hor %d vert %d\n", REG_CX, REG_DX);
		} else if ((REG_AX&0xff)==3) {
			if (mouse_down) mouse_y-=5;
			REG_BX=mouse_btn;
			REG_CX=mouse_x; //col
			REG_DX=mouse_y; //row
//			printf("read mouse %d,%d\n", mouse_x, mouse_y);
			mouse_btn=0;
		} else if ((REG_AX&0xff)==4) {
			//position cursor cx:dx
			mouse_x=REG_CX;
			mouse_y=REG_DX;
//			printf("pos mouse %d,%d\n", mouse_x, mouse_y);
		}
	} else if (intr==0x66 && (REG_AX&0xff)==8) {
//		printf("audio: fill music buffer\n");
		REG_AX=0xff00;  //Note: this seems to indicate *something*... but I have no clue how this affects the code? Super-odd.
//		dump_caller();
	} else if (intr==0x66 && (REG_AX&0xff)==16) { 
		//AL=FORCE POSITION, BX=THE POSITION ret: AL=OLD POSITION
		printf("audio: play jingle in bx: 0x%X\n", REG_BX);
		audio_lock();
		int old_pos=replay_get_sequence_pos(music_replay);
		replay_set_sequence_pos(music_replay, REG_BX);
		audio_unlock();
		REG_AX=old_pos;
	} else if (intr==0x66 && (REG_AX&0xff)==21) {
		printf("audio: get driver caps, AL returns bitfield? Nosound.drv returns 0xa.\n");
		//Note: bit 3 is tested for nosound
//		REG_AX=10; //nosound driver returns this
		REG_AX=8; //nosound driver returns this
	} else if (intr==0x66 && (REG_AX&0xff)==22) {
		printf("audio: ?get amount of data in buffers into dx.ax?\n");
		REG_AX=0;
	} else if (intr==0x66 && (REG_AX&0xff)==17) {
		printf("audio: play sound effect in cl,bl,dl at volume bh\n");
		REG_AX=0;
	} else if (intr==0x66 && (REG_AX&0xff)==18) {
		int adr=(REG_DS*0x10)+REG_DX;
		char name[64]={0};
		for (int i=0; i<64; i++) name[i]=cpu_addr_space_read8(adr+i);
		printf("audio: load mod in ds:dx: %s\n", name);
		REG_AX=0;
	} else if (intr==0x66 && (REG_AX&0xff)==4) {
		printf("audio: play module ?idx is in bx: 0x%X? at rate cx %d (0 if default)\n", REG_BX, REG_CX);
//		audio_lock();
//		replay_set_sequence_pos(music_replay, REG_BX-1);
//		audio_unlock();
		REG_AX=0;
	} else if (intr==0x66 && (REG_AX&0xff)==15) {
		printf("audio: stop play\n");
		REG_AX=0;
	} else if (intr==0x66 && (REG_AX&0xff)==6) {
		printf("set vol in cx?\n");
		REG_AX=0;
	} else if (intr==0x66 && (REG_AX&0xff)==0) {
		printf("deinit sound device\n");
		REG_AX=0;
	} else if (intr==0x66 && (REG_AX&0xff)==11) {
		//note: far call. BL also is... something.
		printf("init vblank interrupt to es:dx\n");
		cb_blank_seg=REG_ES;
		cb_blank_off=REG_DX;
		REG_AX=0;
	} else if (intr==0x66 && (REG_AX&0xff)==12) {
		//note: far call
		printf("init raster interrupt to es:dx, raster in bl or cx?\n");
		cb_raster_seg=REG_ES;
		cb_raster_off=REG_DX;
		cb_raster_int_line=REG_CX/2;
		REG_AX=0;
	} else if (intr==0x66 && (REG_AX&0xff)==19) {
		printf("init jingle handler to es:dx\n");
		cb_jingle_seg=REG_ES;
		cb_jingle_off=REG_DX;
		REG_AX=0;
	} else {
		printf("Unhandled interrupt 0x%X\n", intr);
		dump_regs();
	}
}

int cpu_hlt_handler() {
	printf("CPU halted!\n");
	exit(1);
}

uint16_t force_callback(int seg, int off, int axval) {
	uint16_t ret;
	struct cpu cpu_backup;
	//Save existing registers
	cpu_backup=cpu;
	//set cs:ip to address of callback
	cpu.segregs[regcs]=seg;
	cpu.ip=off;
	cpu.regs.wordregs[regax]=axval;
	//increase sp by four, as if there was a call that pushed the address of the calling function
	//on the stack
	cpu.regs.wordregs[regsp]=cpu.regs.wordregs[regsp]-4;
	int stack_addr=cpu.segregs[regss]*0x10+cpu.regs.wordregs[regsp];
	cpu_addr_space_write8(stack_addr, 0x00);
	cpu_addr_space_write8(stack_addr+1, 0x00);
	cpu_addr_space_write8(stack_addr+2, 0x00);
	cpu_addr_space_write8(stack_addr+3, 0x00);

	//Run the callback until we can see the return address has been popped; this
	//indicates a ret happened.
//	while (cpu.regs.wordregs[regsp]<=cpu_backup.regs.wordregs[regsp]) exec_cpu(1);
	while (cpu.segregs[regcs]!=0 || cpu.ip!=0) trace_run_cpu(1);
	ret=cpu.regs.wordregs[regax];
	//Restore registers
	cpu=cpu_backup;
	return ret;
}

void music_init(const char *fname) {
	FILE *f=fopen(fname, "r");
	if (!f) {
		perror(fname);
		exit(1);
	}
	fseek(f, 0, SEEK_END);
	int len=ftell(f);
	fseek(f, 0, SEEK_SET);
	struct data mod_data;
	mod_data.buffer=malloc(len);
	fread(mod_data.buffer, 1, len, f);
	mod_data.length=len;
	fclose(f);
	char msg[64];
	music_module=module_load(&mod_data, msg);
	if (music_module==NULL) {
		printf("%s: %s\n", fname, msg);
		exit(1);
	}
	music_replay=new_replay(music_module, SAMP_RATE, 0);
	music_mixbuf=malloc(calculate_mix_buf_len(SAMP_RATE)*4);
	music_mixbuf_left=0;
	music_mixbuf_len=0;
}

static void fill_stream_buf(int16_t *stream, int *mixbuf, int len) {
	for (int i=0; i<len; i++) {
		int v=mixbuf[i];
		if (v<-32768) v=-32768;
		if (v>32767) v=32767;
		stream[i]=v;
	}
}

static void audio_cb(void* userdata, uint8_t* streambytes, int len) {
	uint16_t *stream=(uint16_t*)streambytes;
	len=len/2; //because bytes -> words
	int pos=0;
	if (len==0) return;
	if (music_mixbuf_left!=0) {
		pos=music_mixbuf_left;
		fill_stream_buf(stream, &music_mixbuf[music_mixbuf_len-music_mixbuf_left], music_mixbuf_left);
	}
	music_mixbuf_left=0;
	while (pos!=len) {
		music_mixbuf_len=replay_get_audio(music_replay, (int*)music_mixbuf);
		int cplen=music_mixbuf_len;
		if (pos+cplen>len) {
			cplen=len-pos;
			music_mixbuf_left=music_mixbuf_len-cplen;
		}
		fill_stream_buf(&stream[pos], music_mixbuf, cplen);
		pos+=cplen;
	}
}


int frame=0;

void midframe_cb() {
	if (cb_raster_seg!=0) force_callback(cb_raster_seg, cb_raster_off, 0);
}

void vblank_end_cb() {
	frame++;
	gfx_show(vram, pal, vga_ver, 607);
	schedule_add(midframe_cb, (1000000/15000)*cb_raster_int_line, 0);
}

void vblank_evt_cb() {
	if (cb_blank_seg!=0) force_callback(cb_blank_seg, cb_blank_off, 0);
	schedule_add(vblank_end_cb, (1000000/15000)*20, 0);
}

int dos_timer=0;
void pit_tick_evt_cb() {
	dos_timer++;
	cpu_addr_space_write8(0x46c, dos_timer);
	cpu_addr_space_write8(0x46c, dos_timer>>8);
	intcall86(8); //pit interrupt
}


int main(int argc, char** argv) {
	cpu_addr_space_init();
	init_intr_table();
	init_vga_mem();
	gfx_init();
	music_init("../data/TABLE2.MOD");
	init_audio(SAMP_RATE, audio_cb);

	schedule_add(vblank_evt_cb,   1000000/72, 1);

	load_mz("../data/TABLE2.PRG", 0x10000);

	while(1) {
		schedule_run(1000000/72); //about 1 frame
#if DO_TRACE
		if (frame==59) trace_enable(1);
		if (frame==60) {
			while (cpu.ifl==0) trace_run_cpu(10);
			key_pressed=INPUT_F1;
			intcall86(9);
		}
#endif

//		printf("hor %d ver %d start addr %d\n", vga_hor, vga_ver, vga_startaddr);
//		cpu_addr_space_dump();
#if 1
		if (has_looped(music_replay)) {
			printf("Music has looped. Doing jingle callback...\n");
			uint16_t ret=force_callback(cb_jingle_seg, cb_jingle_off, 0);
			audio_lock();
			replay_set_sequence_pos(music_replay, ret&0xff);
			printf("Jingle callback returned 0x%X\n", ret);
			audio_unlock();
		}
#endif
		int key;
		while ((key=gfx_get_key())>0) {
			if (key==INPUT_SPRING) {
				mouse_down=1;
			} else if (key==(INPUT_SPRING|INPUT_RELEASE)) {
				mouse_down=0;
				mouse_btn=1;
			} else if (key==INPUT_TEST) {
				uint16_t ret=force_callback(cb_jingle_seg, cb_jingle_off, 0);
				audio_lock();
				replay_set_sequence_pos(music_replay, ret&0xff);
				audio_unlock();
				printf("Jingle callback returned 0x%X\n", ret);
			} else {
				//wait till interrupts are enabled (not in int)
				while (cpu.ifl==0) trace_run_cpu(10);
				key_pressed=key;
				intcall86(9);
			}
		}
	}
	return 0;
}

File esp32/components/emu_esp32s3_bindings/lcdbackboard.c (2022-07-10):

//Secondary SPI backboard LCD driver
/*
 * ----------------------------------------------------------------------------
 * "THE BEER-WARE LICENSE" (Revision 42):
 * Jeroen Domburg <jeroen@spritesmods.com> wrote this file. As long as you retain 
 * this notice you can do whatever you want with this stuff. If we meet some day, 
 * and you think this stuff is worth it, you can buy me a beer in return. 
 * ----------------------------------------------------------------------------
 */

#include <stdio.h>
#include <stdlib.h>
#include <string.h>
#include "freertos/FreeRTOS.h"
#include "freertos/task.h"
#include "freertos/semphr.h"
#include "esp_system.h"
#include "driver/spi_master.h"
#include "driver/gpio.h"
#include "hiscore.h"
#include "font.h"

#define PIN_NUM_CS	 7
#define PIN_NUM_DC	 15

#define PARALLEL_LINES 8

/*
 The LCD needs a bunch of command/argument values to be initialized. They are stored in this struct.
 No idea about what the values are, I got them from the store I bought the display from.
*/
typedef struct {
	uint8_t cmd;
	uint8_t data[16];
	uint8_t databytes; //No of data in data; bit 7 = delay after set; 0xFF = end of cmds.
} lcd_init_cmd_t;

const lcd_init_cmd_t init_cmds[17]={
	{0xC8, {0xFF, 0x93, 0x42}, 3},
	{0xb6, {0x0a, 0xE0}, 2},
	{0x36, {0x08}, 1},
	{0x3A, {0x55}, 1},
	{0xC0, {0x13, 0x0E}, 2},
	{0xC1, {0x02}, 1},
	{0xC5, {0xCA}, 1},
	{0xB1, {0x00, 0x1B}, 2},
	{0xB4, {0x02}, 1},
	{0xE0, {0x00, 0x02, 0x04, 0x00, 0x11, 0x08, 0x35, 0x79, 0x45, 0x07, 0x0D, 0x09, 0x16, 0x17, 0x0F}, 15},
	{0xE1, {0x00, 0x28, 0x29, 0x02, 0x0F, 0x06, 0x3F, 0x25, 0x55, 0x06, 0x15, 0x0F, 0x38, 0x38, 0x0F}, 15},
	{0x2A, {0x00, 0x00, 0x01, 0x3F}, 4},
	{0x2B, {0x00, 0x00, 0x00, 0xEF}, 4},
	{0x11, {0}, 0x80},
	{0x29, {0}, 0},
	{0x2C, {0}, 0},
};



/* Send a command to the LCD. Uses spi_device_polling_transmit, which waits
until the transfer is complete. */
static void lcd_cmd(spi_device_handle_t spi, const uint8_t cmd) {
	esp_err_t ret;
	spi_transaction_t t;
	memset(&t, 0, sizeof(t));		//Zero out the transaction
	t.length=8;						//Command is 8 bits
	t.tx_buffer=&cmd;				//The data is the cmd itself
	t.user=(void*)0;				//D/C needs to be set to 0
	ret=spi_device_polling_transmit(spi, &t);  //Transmit!
	assert(ret==ESP_OK);			//Should have had no issues.
}

/* Send data to the LCD. Uses spi_device_polling_transmit, which waits until the
transfer is complete */
static void lcd_data(spi_device_handle_t spi, const uint8_t *data, int len) {
	esp_err_t ret;
	spi_transaction_t t;
	if (len==0) return;				//no need to send anything
	memset(&t, 0, sizeof(t));		//Zero out the transaction
	t.length=len*8;					//Len is in bytes, transaction length is in bits.
	t.tx_buffer=data;				//Data
	t.user=(void*)1;				//D/C needs to be set to 1
	ret=spi_device_polling_transmit(spi, &t);  //Transmit!
	assert(ret==ESP_OK);			//Should have had no issues.
}

//This function is called (in irq context!) just before a transmission starts. It will
//set the D/C line to the value indicated in the user field.
void lcd_spi_pre_transfer_callback(spi_transaction_t *t) {
	int dc=(int)t->user;
	gpio_set_level(PIN_NUM_DC, dc);
}

//Initialize the display
static void lcd_init_controller(spi_device_handle_t spi) {
	int cmd=0;
	const lcd_init_cmd_t* lcd_init_cmds=init_cmds;

	//Initialize non-SPI GPIOs
	gpio_config_t cfg = {
		.pin_bit_mask = BIT64(PIN_NUM_DC),
		.mode = GPIO_MODE_OUTPUT,
		.pull_up_en = false,
		.pull_down_en = false,
		.intr_type = GPIO_INTR_DISABLE,
	};
	gpio_config(&cfg);

	//Send all the commands
	while (lcd_init_cmds[cmd].databytes!=0xff) {
		lcd_cmd(spi, lcd_init_cmds[cmd].cmd);
		uint8_t d[16];
		memcpy(d, lcd_init_cmds[cmd].data, 16);
		lcd_data(spi, d, lcd_init_cmds[cmd].databytes&0x1F);
		if (lcd_init_cmds[cmd].databytes&0x80) {
			vTaskDelay(pdMS_TO_TICKS(100));
		}
		cmd++;
	}
}
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

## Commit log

2022-01-30 Add keyboard, fix audio
    [cpu.c, main.c]
2022-03-19 Omg, found the bug, it was in the line that checks if a callback has ended yet. Anyway, the frantic debugging session also lead to some refactoring and cleaning up, so not all is lost.
    [main.c]
2022-03-20 Convert into esp32 project
    [partitions.csv]
2022-04-20 Move to octal psram
    [partitions.csv]
2022-05-02 Emu works, backboard LCD is barebones but works, added menu
    [partitions.csv]
2022-06-17 fix esp32, add table images to bin
    [gfx_esp32.c]
2022-06-24 esp32 code fix; move to new hardware
    [gfx_esp32.c, lcd.c, lcdbackboard.c]
2022-07-09 Restructure repo to entire project; add PCB artwork
    [partitions.csv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]
2022-07-09 Split sdkconfig into defaults for esp32 and esp32s3
2022-07-09 Add OpenSCAD case design
    [case.scad]
2022-07-09 Add config screen, allow for plunger calibration
2022-07-09 Add support for tilting the table using accelerometer
2022-07-10 Add pdf versions of schematics
2022-07-17 Fix things I bodged in my prototype
    [pbf-mainpcb.kicad_pcb, pbf-mainpcb.kicad_sch]
2023-12-05 added readme description, changed zener 12V -> 15V
    [pbf-mainpcb.kicad_sch]
2023-12-11 Fix porting issues; update audio driver to new api
    [lcd.c]
2023-12-11 Make it more clearer that you cannot use octal psram
    [pbf-mainpcb.kicad_sch]

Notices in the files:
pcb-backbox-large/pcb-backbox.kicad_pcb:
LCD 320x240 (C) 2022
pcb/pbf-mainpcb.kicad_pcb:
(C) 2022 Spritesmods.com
